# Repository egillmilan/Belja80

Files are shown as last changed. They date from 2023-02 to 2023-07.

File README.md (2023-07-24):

# Belja80
 
TKL keyboard based on the RP2040 microcontroller. Compatible with ANSI and ISO layout.
78338884-2CD3-49FE-B128-DA2AC7E8922D
CA066DF3-226C-4CC9-AC3D-376DD7F449F3
207D5793-591D-41C7-A5E0-8D16D3B497DB

# Flashing instructions
* Plug the keyboard into a computer and a drive named "RP2040" should appear. It might be necessary to hold down the boot button while plugging in the board for the drive to appear.
* Install [Adafruit circuitpython for the Raspberry Pi Pico](https://circuitpython.org/board/raspberry_pi_pico/), version 8 or newer. This is done by copying the .uf2 file to the RP2040 drive. The drive will dissapear briefly and a drive named "CIRCUITPY" will appear.
* Copy the folder named "kmk" from the [kmk_firmware-master repository](https://github.com/KMKfw/kmk_firmware) to the CIRCUIUTPY drive.
* Copy the supplied python files in the "Belja80_firmware" folder to the CIRCUITPY drive.

The keyboard should now work. When plugging in the keyboard next time, the board will not appear as a drive. To let the keyboard appear as a drive, hold in Esc while plugging the keyboard into your computer.

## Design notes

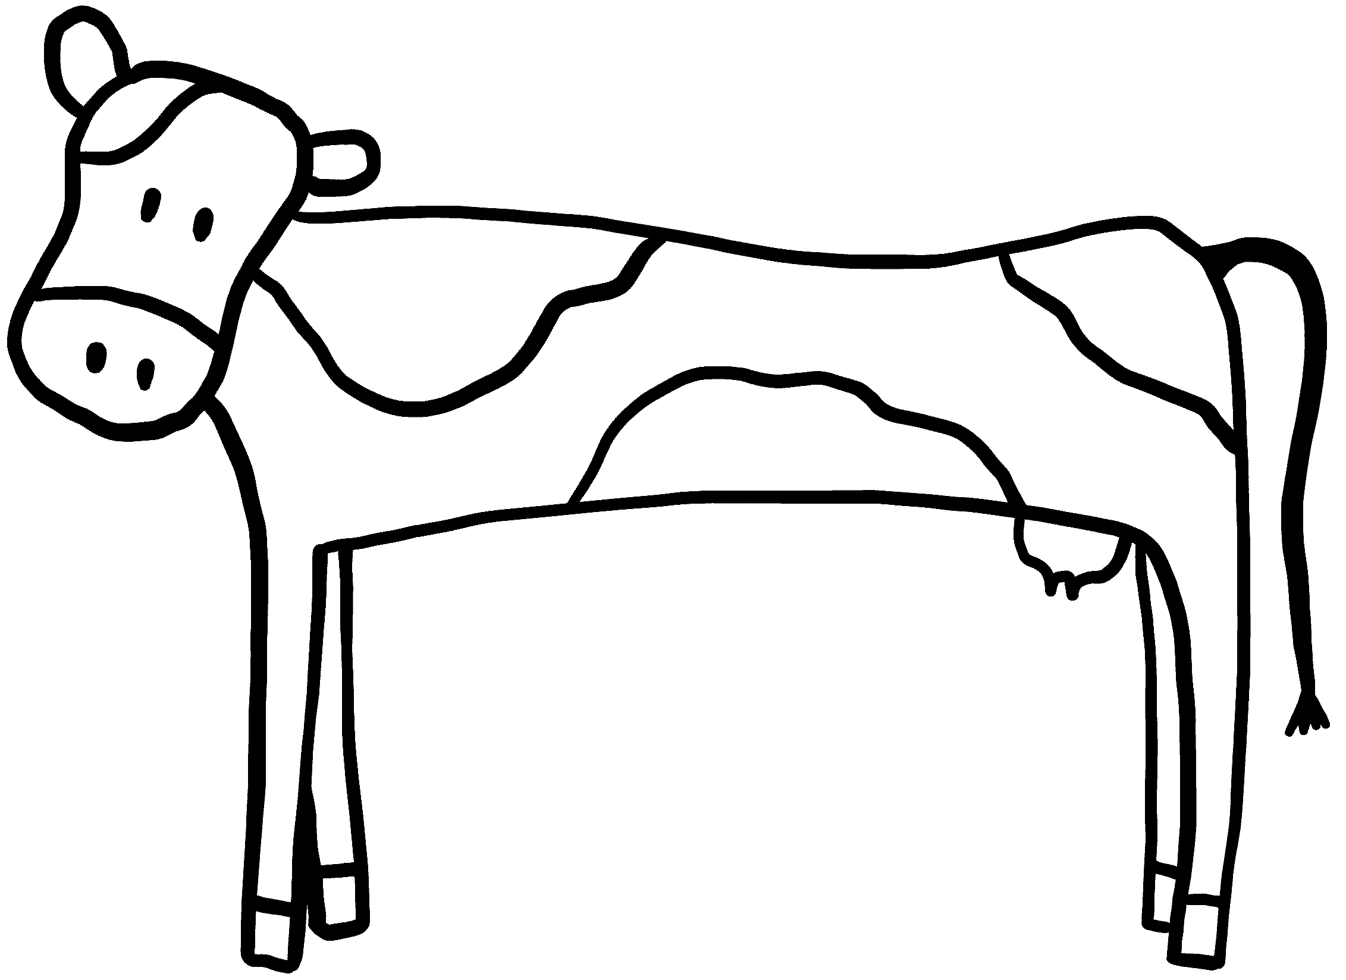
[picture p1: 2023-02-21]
belja80.jpg

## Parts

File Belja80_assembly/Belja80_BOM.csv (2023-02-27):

Comment | Designator | Footprint | LCSC Part Number
1uF | C1, C14 | 402 | C52923
30p | C2, C8 | 402 | C1570
100nF | C3, C4, C7, C9, C10, C11, C12, C13, C15, C16 | 402 | C1525
22uF | C5, C6 | CASE-A-3216 | C97062
SM4007PL | D1, D2, D3, D4, D5, D6, D7, D8, D9, D10, D11, D12, D13, D14, D15, D16, D17, D18, D19, D20, D21, D22, D23, D24, D25, D26, D27, D28, D29, D30, D31, D32, D33, D34, D35, D36, D37, D38, D39, D40, D41, D42, D43, D44, D45, D46, D47, D48, D49, D50, D51, D52, D53, D54, D55, D56, D57, D58, D59, D60, D61, D62, D63, D64, D65, D66, D67, D68, D69, D70, D71, D72, D73, D74, D75, D76, D77, D78, D79, D80, D81, D82, D83, D84, D85, D86, D87, D88, D89 | SOD-123FL | C64898
Green LED | D90 | 603 | C72043
500mA | F1 | 1206 | C206992
220R@100MHz | FB1 | 603 | C80165
USB_C_Receptacle | J1 | SMD | C2760486
1k | R1, R2, R8 | 402 | C11702
27R | R3, R6 | 402 | C226392
5k1 | R4, R5 | 603 | C23186
10k | R9 | 603 | C25804
TS-1187A-B-A-B | SW92,SW93 | SMD | C318884
RP2040 | U1 | LQFN-56(7x7) | C2040
AMS1117-3.3 | U2 | SOT-223-3 | C6186
W25Q16JVSSIQ | U3 | SOIC-8-208mil | C82317
12MHz | Y1 | SMD3225-4P | C9002

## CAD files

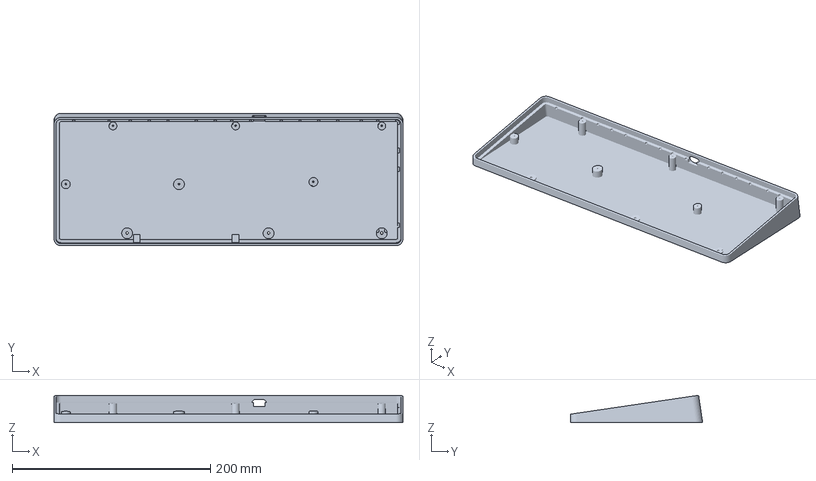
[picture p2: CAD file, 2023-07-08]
Belja80_case_3D_files/Belja80_Case_v2_2_whole.3mf
352.5 x 133.7 x 27.7 mm

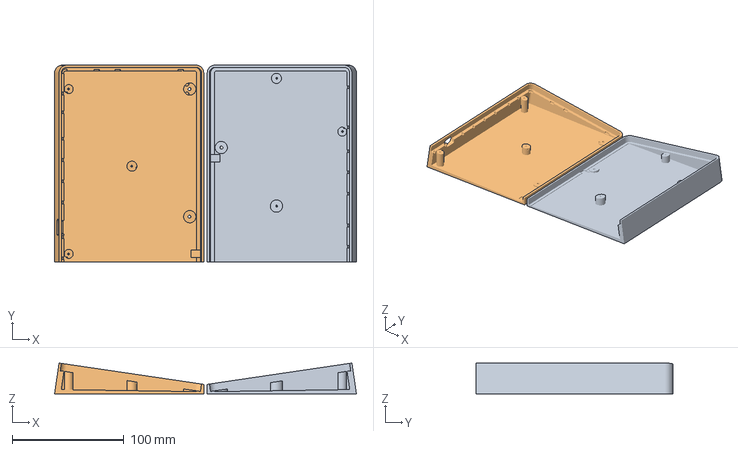
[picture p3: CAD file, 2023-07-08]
Belja80_case_3D_files/Belja80_Case_v2_2_split.3mf
270.5 x 176.2 x 27.7 mm
Case_L
Case_R

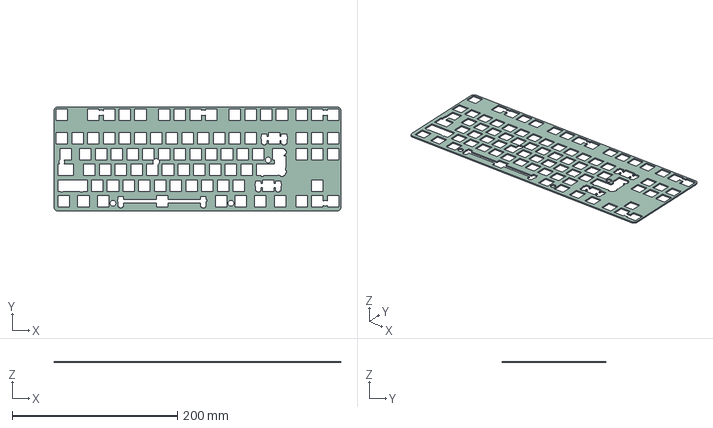
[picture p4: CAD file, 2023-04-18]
Belja80_plate/Belja80_plate.step
347.7 x 126.2 x 1.60 mm

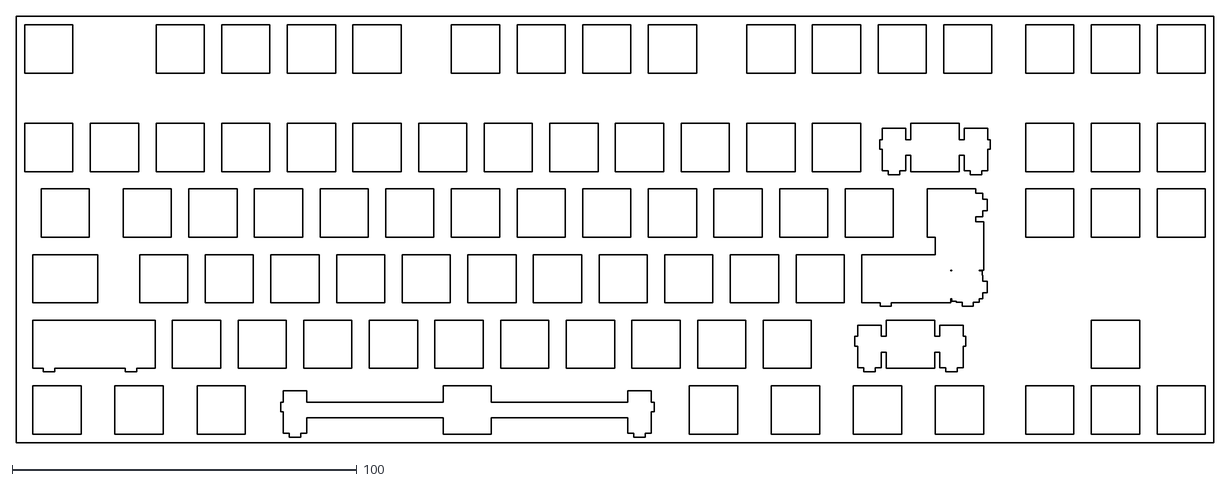
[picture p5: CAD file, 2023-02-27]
Belja80_plate/belja80_KLE.dxf
347.7 x 123.8

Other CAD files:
Belja80_case_3D_files/Belja80_Case_v2_2_split.stl
Belja80_case_3D_files/Belja80_Case_v2_2_whole.stl

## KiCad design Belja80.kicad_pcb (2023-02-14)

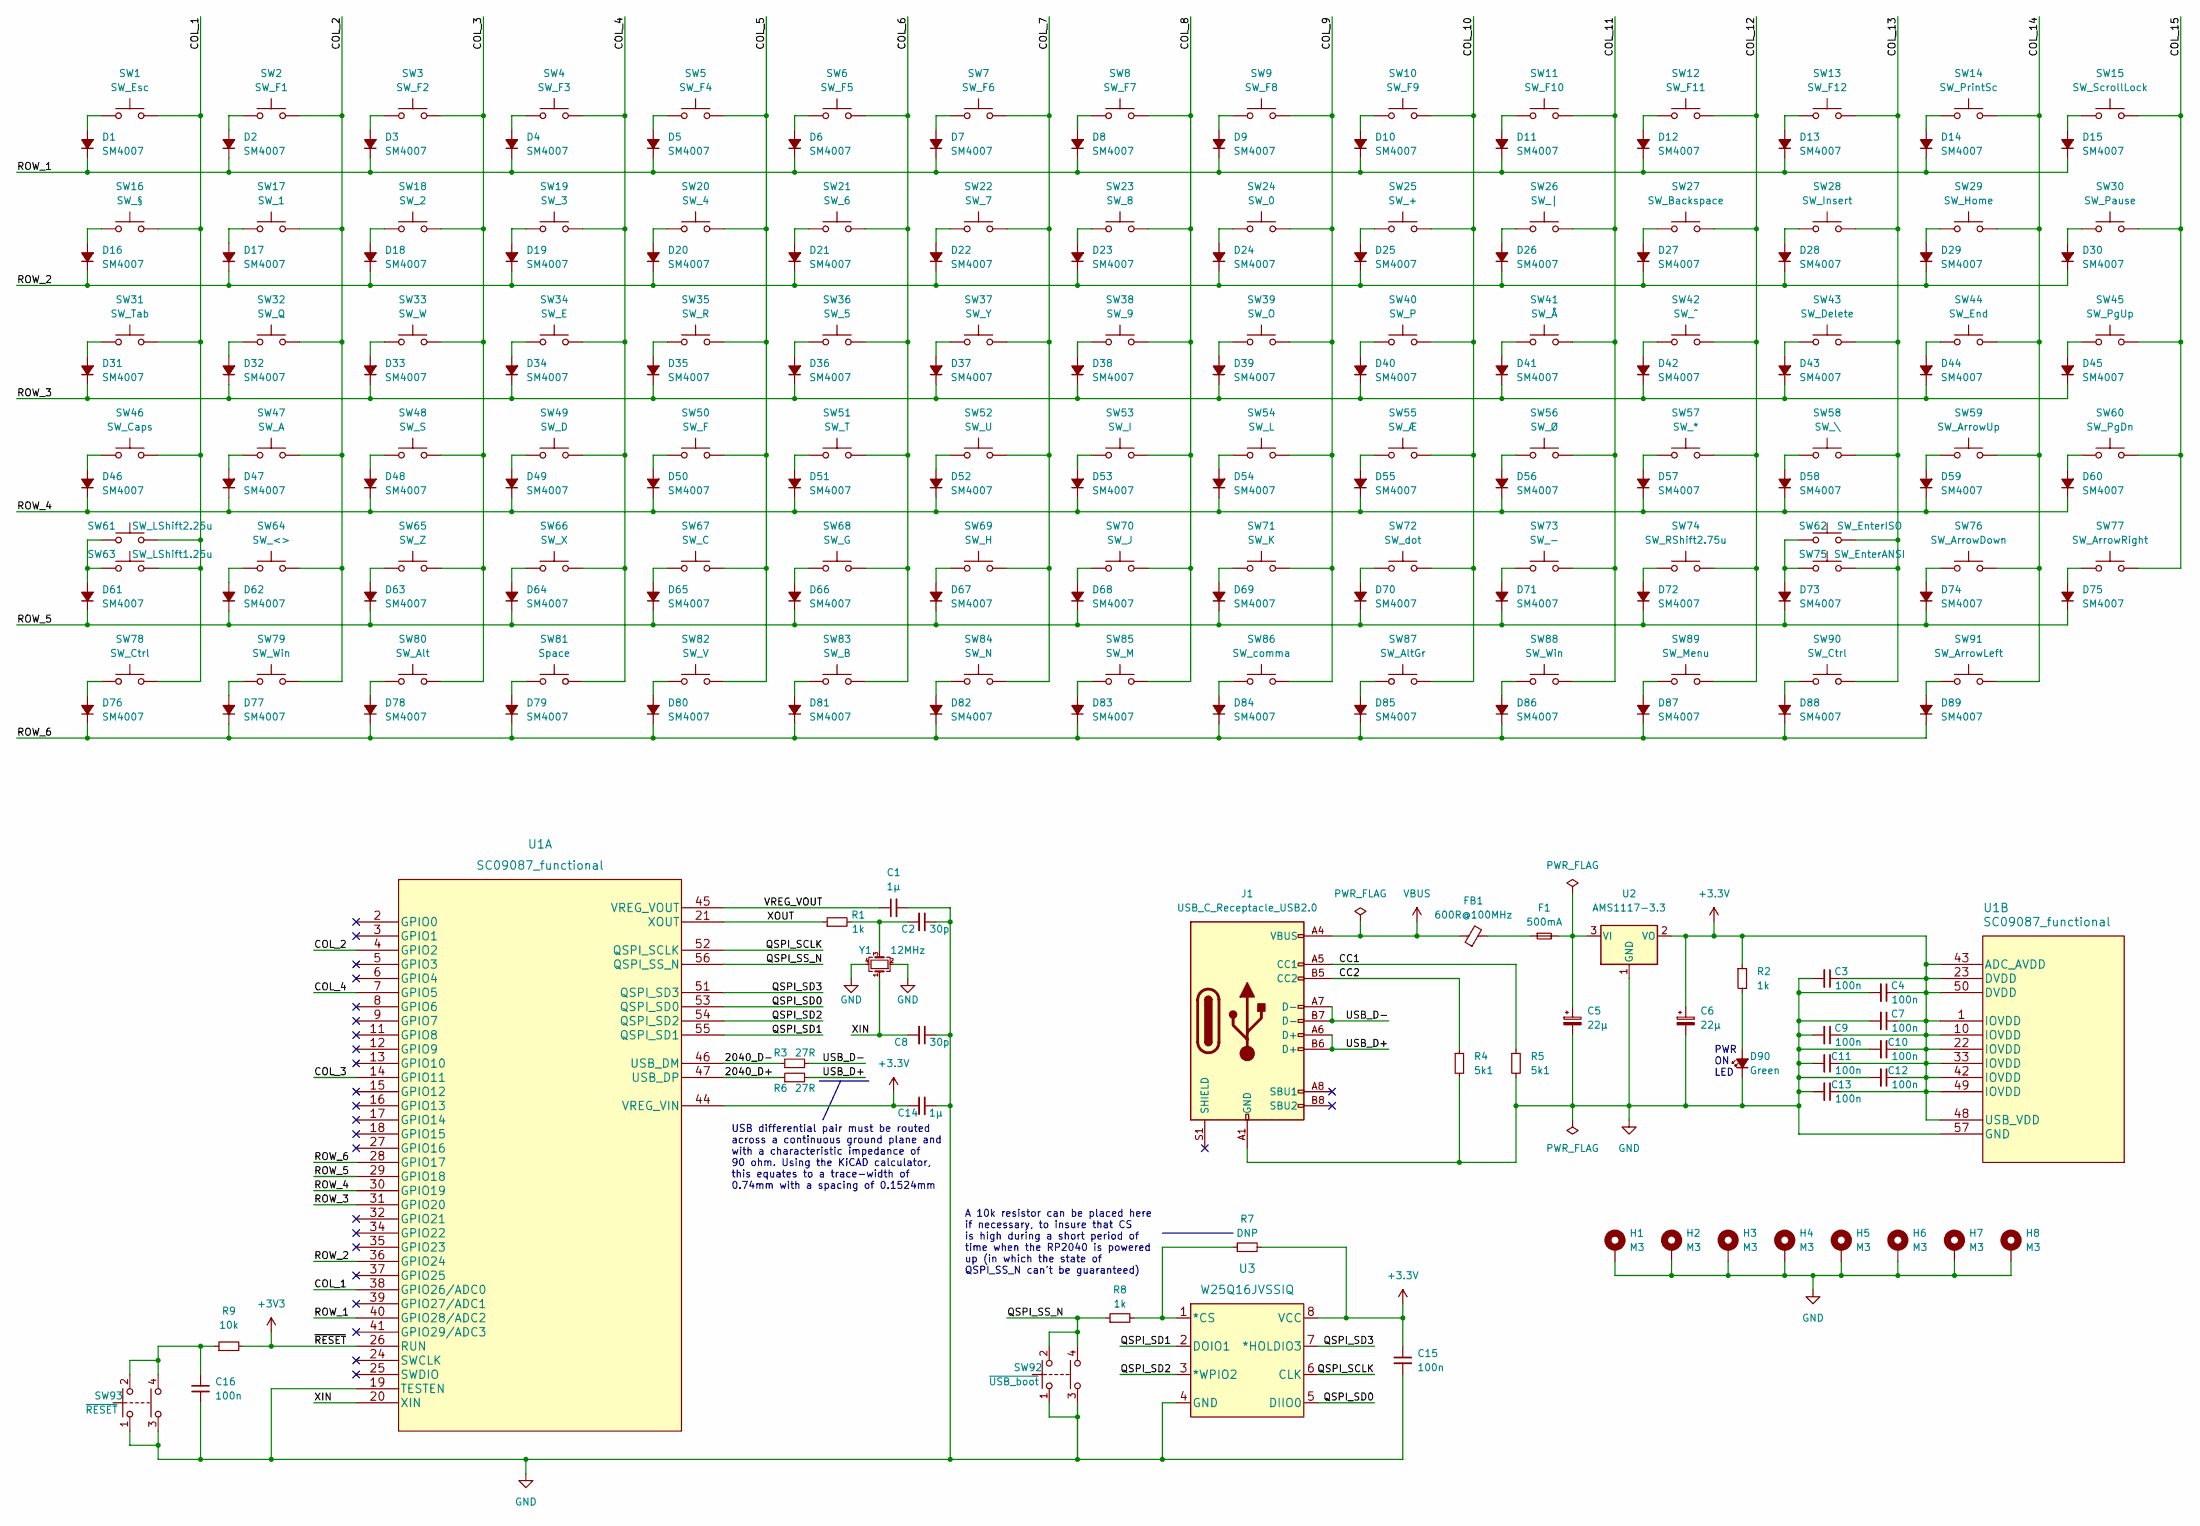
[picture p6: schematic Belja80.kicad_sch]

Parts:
C1, C14: 1µ; C_0402_1005Metric
C2, C8: 30p; C_0402_1005Metric
C3, C4, C7, C9, C10, C11, C12, C13, C15, C16: 100n; C_0402_1005Metric
C5, C6: 22µ; CP_EIA-3216-18_Kemet-A
D1, D2, D3, D4, D5, D6, D7, D8, D9, D10, D11, D12, D13, D14, D15, D16, D17, D18, D19, D20, D21, D22, D23, D24, D25, D26, D27, D28, D29, D30, D31, D32, D33, D34, D35, D36, D37, D38, D39, D40, D41, D42, D43, D44, D45, D46, D47, D48, D49, D50, D51, D52, D53, D54, D55, D56, D57, D58, D59, D60, D61, D62, D63, D64, D65, D66, D67, D68, D69, D70, D71, D72, D73, D74, D75, D76, D77, D78, D79, D80, D81, D82, D83, D84, D85, D86, D87, D88, D89: SM4007; D_SOD-123F
D90: Green; LED_0603_1608Metric
F1: 500mA; Fuse_1206_3216Metric
FB1: 600R@100MHz; L_0603_1608Metric
H1, H2, H3, H4, H5, H6, H7, H8: M3; MountingHole_3.2mm_M3_Pad_Via
J1: USB_C_Receptacle_USB2.0; USB_C_Receptacle_GCT_USB4085
R1, R2, R8: 1k; R_0603_1608Metric
R3, R6: 27R; R_0603_1608Metric
R4, R5: 5k1; R_0603_1608Metric
R7: DNP; R_0603_1608Metric
R9: 10k; R_0603_1608Metric
SW1: SW_Esc; SW_Cherry_MX_1.00u_PCB
SW2: SW_F1; SW_Cherry_MX_1.00u_PCB
SW3: SW_F2; SW_Cherry_MX_1.00u_PCB
SW4: SW_F3; SW_Cherry_MX_1.00u_PCB
SW5: SW_F4; SW_Cherry_MX_1.00u_PCB
SW6: SW_F5; SW_Cherry_MX_1.00u_PCB
SW7: SW_F6; SW_Cherry_MX_1.00u_PCB
SW8: SW_F7; SW_Cherry_MX_1.00u_PCB
SW9: SW_F8; SW_Cherry_MX_1.00u_PCB
SW10: SW_F9; SW_Cherry_MX_1.00u_PCB
SW11: SW_F10; SW_Cherry_MX_1.00u_PCB
SW12: SW_F11; SW_Cherry_MX_1.00u_PCB
SW13: SW_F12; SW_Cherry_MX_1.00u_PCB
SW14: SW_PrintSc; SW_Cherry_MX_1.00u_PCB
SW15: SW_ScrollLock; SW_Cherry_MX_1.00u_PCB
SW16: SW_§; SW_Cherry_MX_1.00u_PCB
SW17: SW_1; SW_Cherry_MX_1.00u_PCB
SW18: SW_2; SW_Cherry_MX_1.00u_PCB
SW19: SW_3; SW_Cherry_MX_1.00u_PCB
SW20: SW_4; SW_Cherry_MX_1.00u_PCB
SW21: SW_6; SW_Cherry_MX_1.00u_PCB
SW22: SW_7; SW_Cherry_MX_1.00u_PCB
SW23: SW_8; SW_Cherry_MX_1.00u_PCB
SW24: SW_0; SW_Cherry_MX_1.00u_PCB
SW25: SW_+; SW_Cherry_MX_1.00u_PCB
SW26: SW_|; SW_Cherry_MX_1.00u_PCB
SW27: SW_Backspace; SW_Cherry_MX_2.00u_PCB
SW28: SW_Insert; SW_Cherry_MX_1.00u_PCB
SW29: SW_Home; SW_Cherry_MX_1.00u_PCB
SW30: SW_Pause; SW_Cherry_MX_1.00u_PCB
SW31: SW_Tab; SW_Cherry_MX_1.50u_PCB
SW32: SW_Q; SW_Cherry_MX_1.00u_PCB
SW33: SW_W; SW_Cherry_MX_1.00u_PCB
SW34: SW_E; SW_Cherry_MX_1.00u_PCB
SW35: SW_R; SW_Cherry_MX_1.00u_PCB
SW36: SW_5; SW_Cherry_MX_1.00u_PCB
SW37: SW_Y; SW_Cherry_MX_1.00u_PCB
SW38: SW_9; SW_Cherry_MX_1.00u_PCB
SW39: SW_O; SW_Cherry_MX_1.00u_PCB
SW40: SW_P; SW_Cherry_MX_1.00u_PCB
SW41: SW_Å; SW_Cherry_MX_1.00u_PCB
SW42: SW_^; SW_Cherry_MX_1.00u_PCB
SW43: SW_Delete; SW_Cherry_MX_1.00u_PCB
SW44: SW_End; SW_Cherry_MX_1.00u_PCB
SW45: SW_PgUp; SW_Cherry_MX_1.00u_PCB
SW46: SW_Caps; SW_Cherry_MX_1.75u_PCB
SW47: SW_A; SW_Cherry_MX_1.00u_PCB
SW48: SW_S; SW_Cherry_MX_1.00u_PCB
SW49: SW_D; SW_Cherry_MX_1.00u_PCB
SW50: SW_F; SW_Cherry_MX_1.00u_PCB
SW51: SW_T; SW_Cherry_MX_1.00u_PCB
SW52: SW_U; SW_Cherry_MX_1.00u_PCB
SW53: SW_I; SW_Cherry_MX_1.00u_PCB
SW54: SW_L; SW_Cherry_MX_1.00u_PCB
SW55: SW_Æ; SW_Cherry_MX_1.00u_PCB
SW56: SW_Ø; SW_Cherry_MX_1.00u_PCB
SW57: SW_*; SW_Cherry_MX_1.00u_PCB
SW58: SW_\; SW_Cherry_MX_1.50u_PCB
SW59: SW_ArrowUp; SW_Cherry_MX_1.00u_PCB
SW60: SW_PgDn; SW_Cherry_MX_1.00u_PCB
SW61: SW_LShift2.25u; SW_Cherry_MX_2.25u_PCB
SW62: SW_EnterISO; SW_Cherry_MX_ISOEnter_PCB
SW63: SW_LShift1.25u; SW_Cherry_MX_1.25u_PCB
SW64: SW_<>; SW_Cherry_MX_1.00u_PCB
SW65: SW_Z; SW_Cherry_MX_1.00u_PCB
SW66: SW_X; SW_Cherry_MX_1.00u_PCB
SW67: SW_C; SW_Cherry_MX_1.00u_PCB
SW68: SW_G; SW_Cherry_MX_1.00u_PCB
SW69: SW_H; SW_Cherry_MX_1.00u_PCB
SW70: SW_J; SW_Cherry_MX_1.00u_PCB
SW71: SW_K; SW_Cherry_MX_1.00u_PCB
SW72: SW_dot; SW_Cherry_MX_1.00u_PCB
SW73: SW_-; SW_Cherry_MX_1.00u_PCB
SW74: SW_RShift2.75u; SW_Cherry_MX_2.75u_PCB
SW75: SW_EnterANSI; SW_Cherry_MX_2.25u_PCB
SW76: SW_ArrowDown; SW_Cherry_MX_1.00u_PCB
SW77: SW_ArrowRight; SW_Cherry_MX_1.00u_PCB
SW78, SW90: SW_Ctrl; SW_Cherry_MX_1.25u_PCB
SW79, SW88: SW_Win; SW_Cherry_MX_1.25u_PCB
SW80: SW_Alt; SW_Cherry_MX_1.25u_PCB
SW81: Space; SW_Cherry_MX_6.25u_PCB
SW82: SW_V; SW_Cherry_MX_1.00u_PCB
SW83: SW_B; SW_Cherry_MX_1.00u_PCB
SW84: SW_N; SW_Cherry_MX_1.00u_PCB
SW85: SW_M; SW_Cherry_MX_1.00u_PCB
SW86: SW_comma; SW_Cherry_MX_1.00u_PCB
SW87: SW_AltGr; SW_Cherry_MX_1.25u_PCB
SW89: SW_Menu; SW_Cherry_MX_1.25u_PCB
SW91: SW_ArrowLeft; SW_Cherry_MX_1.00u_PCB
SW92: ~{USB_boot}; SW_TS-1187A-B-A-B
SW93: ~{RESET}; SW_TS-1187A-B-A-B
U1: SC09087_functional; SC09087
U2: AMS1117-3.3; SOT-223-3_TabPin2
U3: W25Q16JVSSIQ
Y1: 12MHz; Crystal_SMD_3225-4Pin_3.2x2.5mm

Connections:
/2040_D+: R6.1, U1.47 (USB_DP)
/2040_D-: R3.1, U1.46 (USB_DM)
/CC1: J1.A5 (CC1), R5.1
/CC2: J1.B5 (CC2), R4.1
/COL_1: SW1.2, SW16.2, SW31.2, SW46.2, SW61.2, SW63.2, SW78.2, U1.38 (GPIO26/ADC0)
/COL_2: SW2.2, SW17.2, SW32.2, SW47.2, SW64.2, SW79.2, U1.4 (GPIO2)
/COL_3: SW3.2, SW18.2, SW33.2, SW48.2, SW65.2, SW80.2, U1.14 (GPIO11)
/COL_4: SW4.2, SW19.2, SW34.2, SW49.2, SW66.2, SW81.2, U1.7 (GPIO5)
/COL_5: SW5.2, SW20.2, SW35.2, SW50.2, SW67.2, SW82.2
/COL_6: SW6.2, SW21.2, SW36.2, SW51.2, SW68.2, SW83.2
/COL_7: SW7.2, SW22.2, SW37.2, SW52.2, SW69.2, SW84.2
/COL_8: SW8.2, SW23.2, SW38.2, SW53.2, SW70.2, SW85.2
/COL_9: SW9.2, SW24.2, SW39.2, SW54.2, SW71.2, SW86.2
/COL_10: SW10.2, SW25.2, SW40.2, SW55.2, SW72.2, SW87.2
/COL_11: SW11.2, SW26.2, SW41.2, SW56.2, SW73.2, SW88.2
/COL_12: SW12.2, SW27.2, SW42.2, SW57.2, SW74.2, SW89.2
/COL_13: SW13.2, SW28.2, SW43.2, SW58.2, SW62.2, SW75.2, SW90.2
/COL_14: SW14.2, SW29.2, SW44.2, SW59.2, SW76.2, SW91.2
/COL_15: SW15.2, SW30.2, SW45.2, SW60.2, SW77.2
/QSPI_SCLK: U1.52 (QSPI_SCLK), U3.6 (CLK)
/QSPI_SD0: U1.53 (QSPI_SD0), U3.5 (DIIO0)
/QSPI_SD1: U1.55 (QSPI_SD1), U3.2 (DOIO1)
/QSPI_SD2: U1.54 (QSPI_SD2), U3.3 (*WPIO2)
/QSPI_SD3: U1.51 (QSPI_SD3), U3.7 (*HOLDIO3)
/QSPI_SS_N: R8.1, SW92.2, SW92.4, U1.56 (QSPI_SS_N)
/ROW_1: D1.1 (K), D2.1 (K), D3.1 (K), D4.1 (K), D5.1 (K), D6.1 (K), D7.1 (K), D8.1 (K), D9.1 (K), D10.1 (K), D11.1 (K), D12.1 (K), D13.1 (K), D14.1 (K), D15.1 (K), U1.40 (GPIO28/ADC2)
/ROW_2: D16.1 (K), D17.1 (K), D18.1 (K), D19.1 (K), D20.1 (K), D21.1 (K), D22.1 (K), D23.1 (K), D24.1 (K), D25.1 (K), D26.1 (K), D27.1 (K), D28.1 (K), D29.1 (K), D30.1 (K), U1.36 (GPIO24)
/ROW_3: D31.1 (K), D32.1 (K), D33.1 (K), D34.1 (K), D35.1 (K), D36.1 (K), D37.1 (K), D38.1 (K), D39.1 (K), D40.1 (K), D41.1 (K), D42.1 (K), D43.1 (K), D44.1 (K), D45.1 (K), U1.31 (GPIO20)
/ROW_4: D46.1 (K), D47.1 (K), D48.1 (K), D49.1 (K), D50.1 (K), D51.1 (K), D52.1 (K), D53.1 (K), D54.1 (K), D55.1 (K), D56.1 (K), D57.1 (K), D58.1 (K), D59.1 (K), D60.1 (K), U1.30 (GPIO19)
/ROW_5: D61.1 (K), D62.1 (K), D63.1 (K), D64.1 (K), D65.1 (K), D66.1 (K), D67.1 (K), D68.1 (K), D69.1 (K), D70.1 (K), D71.1 (K), D72.1 (K), D73.1 (K), D74.1 (K), D75.1 (K), U1.29 (GPIO18)
/ROW_6: D76.1 (K), D77.1 (K), D78.1 (K), D79.1 (K), D80.1 (K), D81.1 (K), D82.1 (K), D83.1 (K), D84.1 (K), D85.1 (K), D86.1 (K), D87.1 (K), D88.1 (K), D89.1 (K), U1.28 (GPIO17)
/USB_D+: J1.A6 (D+), J1.B6 (D+), R6.2
/USB_D-: J1.A7 (D-), J1.B7 (D-), R3.2
/XIN: C8.2, U1.20 (XIN), Y1.1
/XOUT: R1.1, U1.21 (XOUT)
GND: C1.2, C2.1, C3.2, C4.2, C5.2, C6.2, C7.2, C8.1, C9.2, C10.2, C11.2, C12.2, C13.2, C14.2, C15.2, C16.2, D90.1 (K), H1.1, H2.1, H3.1, H4.1, H5.1, H6.1, H7.1, H8.1, J1.A1 (GND), J1.A12 (GND), J1.B1 (GND), J1.B12 (GND), R4.2, R5.2, SW92.1, SW92.3, SW93.1, SW93.3, U1.19 (TESTEN), U1.57 (GND), U2.1 (GND), U3.4 (GND), Y1.2, Y1.4
unnamed: C2.2, R1.2, Y1.3
unnamed: C16.1, R9.1, SW93.2, SW93.4
unnamed: D1.2 (A), SW1.1
unnamed: D2.2 (A), SW2.1
unnamed: D3.2 (A), SW3.1
unnamed: D4.2 (A), SW4.1
unnamed: D5.2 (A), SW5.1
unnamed: D6.2 (A), SW6.1
unnamed: D7.2 (A), SW7.1
unnamed: D8.2 (A), SW8.1
unnamed: D9.2 (A), SW9.1
unnamed: D10.2 (A), SW10.1
unnamed: D11.2 (A), SW11.1
unnamed: D12.2 (A), SW12.1
unnamed: D13.2 (A), SW13.1
unnamed: D14.2 (A), SW14.1
unnamed: D15.2 (A), SW15.1
unnamed: D16.2 (A), SW16.1
unnamed: D17.2 (A), SW17.1
unnamed: D18.2 (A), SW18.1
unnamed: D19.2 (A), SW19.1
unnamed: D20.2 (A), SW20.1
unnamed: D21.2 (A), SW21.1
unnamed: D22.2 (A), SW22.1
unnamed: D23.2 (A), SW23.1
unnamed: D24.2 (A), SW24.1
unnamed: D25.2 (A), SW25.1
unnamed: D26.2 (A), SW26.1
unnamed: D27.2 (A), SW27.1
unnamed: D28.2 (A), SW28.1
unnamed: D29.2 (A), SW29.1
unnamed: D30.2 (A), SW30.1
unnamed: D31.2 (A), SW31.1
unnamed: D32.2 (A), SW32.1
unnamed: D33.2 (A), SW33.1
unnamed: D34.2 (A), SW34.1
unnamed: D35.2 (A), SW35.1
unnamed: D36.2 (A), SW36.1
unnamed: D37.2 (A), SW37.1
unnamed: D38.2 (A), SW38.1
unnamed: D39.2 (A), SW39.1
unnamed: D40.2 (A), SW40.1
unnamed: D41.2 (A), SW41.1
unnamed: D42.2 (A), SW42.1
unnamed: D43.2 (A), SW43.1
unnamed: D44.2 (A), SW44.1
unnamed: D45.2 (A), SW45.1
unnamed: D46.2 (A), SW46.1
unnamed: D47.2 (A), SW47.1
unnamed: D48.2 (A), SW48.1
unnamed: D49.2 (A), SW49.1
unnamed: D50.2 (A), SW50.1
unnamed: D51.2 (A), SW51.1
unnamed: D52.2 (A), SW52.1
unnamed: D53.2 (A), SW53.1
unnamed: D54.2 (A), SW54.1
unnamed: D55.2 (A), SW55.1
unnamed: D56.2 (A), SW56.1
unnamed: D57.2 (A), SW57.1
unnamed: D58.2 (A), SW58.1
unnamed: D59.2 (A), SW59.1
unnamed: D60.2 (A), SW60.1
unnamed: D61.2 (A), SW61.1, SW63.1
unnamed: D62.2 (A), SW64.1
unnamed: D63.2 (A), SW65.1
unnamed: D64.2 (A), SW66.1
unnamed: D65.2 (A), SW67.1
unnamed: D66.2 (A), SW68.1
unnamed: D67.2 (A), SW69.1
unnamed: D68.2 (A), SW70.1
unnamed: D69.2 (A), SW71.1
unnamed: D70.2 (A), SW72.1
unnamed: D71.2 (A), SW73.1
unnamed: D72.2 (A), SW74.1
unnamed: D73.2 (A), SW62.1, SW75.1
unnamed: D74.2 (A), SW76.1
unnamed: D75.2 (A), SW77.1
unnamed: D76.2 (A), SW78.1
unnamed: D77.2 (A), SW79.1
unnamed: D78.2 (A), SW80.1
unnamed: D79.2 (A), SW81.1
unnamed: D80.2 (A), SW82.1
unnamed: D81.2 (A), SW83.1
unnamed: D82.2 (A), SW84.1
unnamed: D83.2 (A), SW85.1
unnamed: D84.2 (A), SW86.1
unnamed: D85.2 (A), SW87.1
unnamed: D86.2 (A), SW88.1
unnamed: D87.2 (A), SW89.1
unnamed: D88.2 (A), SW90.1
unnamed: D89.2 (A), SW91.1
unnamed: D90.2 (A), R2.2
unnamed: F1.1, FB1.2
unnamed: C5.1, F1.2, U2.3 (VI)
unnamed: R7.1, R8.2, U3.1 (*CS)
VBUS: FB1.1, J1.A4 (VBUS), J1.A9 (VBUS), J1.B4 (VBUS), J1.B9 (VBUS)

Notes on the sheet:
PWR ON LED
A 10k resistor can be placed here if necessary, to insure that CS is high during a short period of time when the RP2040 is powered up (in which the state of QSPI_SS_N can't be guaranteed)
USB differential pair must be routed across a continuous ground plane and with a characteristic impedance of 90 ohm. Using the KiCAD calculator, this equates to a trace-width of 0.74mm with a spacing of 0.1524mm

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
Board: 2 copper layers, 223 parts (124 on the bottom side), 134 nets, no tracks yet.

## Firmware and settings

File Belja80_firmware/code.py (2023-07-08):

#ISO LAYOUT

import microcontroller as uC

from kb import KMKKeyboard
from kmk.keys import KC

keyboard = KMKKeyboard()

keyboard.keymap = [
    [KC.ESC,    KC.F1,      KC.F2,      KC.F3,  KC.F4,  KC.F5,  KC.F6,  KC.F7,  KC.F8,      KC.F9,      KC.F10,     KC.F11,     KC.F12,     KC.PSCR,    KC.SLCK,
     KC.GRV,    KC.N1,      KC.N2,      KC.N3,  KC.N4,  KC.N6,  KC.N7,  KC.N8,  KC.N0,      KC.MINS,    KC.EQL,     KC.BSPC,    KC.INS,     KC.HOME,    KC.PAUS,
     KC.TAB,    KC.Q,       KC.W,       KC.E,   KC.R,   KC.N5,  KC.Y,   KC.N9,  KC.O,       KC.P,       KC.LBRC,    KC.RBRC,    KC.DEL,     KC.END,     KC.PGUP,
     KC.CAPS,   KC.A,       KC.S,       KC.D,   KC.F,   KC.T,   KC.U,   KC.I,   KC.L,       KC.SCLN,    KC.QUOT,    KC.NUHS,    KC.NO,      KC.UP,      KC.PGDN,
     KC.LSFT,   KC.NUBS,    KC.Z,       KC.X,   KC.C,   KC.G,   KC.H,   KC.J,   KC.K,       KC.DOT,     KC.SLSH,    KC.RSFT,    KC.ENT,     KC.DOWN,    KC.RGHT,
     KC.LCTL,   KC.LGUI,    KC.LALT,    KC.SPC, KC.V,   KC.B,   KC.N,   KC.M,   KC.COMM,    KC.RALT,    KC.RGUI,    KC.APP,     KC.RCTL,    KC.LEFT,    KC.NO,
    ]
]

if __name__ == '__main__':
    keyboard.go()

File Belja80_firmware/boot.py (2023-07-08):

import supervisor
import board
import digitalio
import storage
import usb_cdc
import usb_hid

from kb import KMKKeyboard
from kmk.scanners import DiodeOrientation


# If this key is held during boot, don't run the code which hides the storage and disables serial
# This will use the first row/col pin. Feel free to change it if you want it to be another pin
col = digitalio.DigitalInOut(KMKKeyboard.col_pins[0])
row = digitalio.DigitalInOut(KMKKeyboard.row_pins[0])

if KMKKeyboard.diode_orientation == DiodeOrientation.COLUMNS:
    col.switch_to_output(value=True)
    row.switch_to_input(pull=digitalio.Pull.DOWN)
else:
    col.switch_to_input(pull=digitalio.Pull.DOWN)
    row.switch_to_output(value=True)

if not row.value:
    storage.disable_usb_drive()
    # Equivalent to usb_cdc.enable(console=False, data=False)
    usb_cdc.disable()
    usb_hid.enable((usb_hid.Device.KEYBOARD),boot_device=1)
    # usb_hid.enable((usb_hid.Device.KEYBOARD,))

row.deinit()
col.deinit()

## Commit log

2023-02-14 Rough layout
    [Belja80.kicad_pcb]
2023-02-18 Component layout
    [Belja80.kicad_sch]
2023-02-20 routing µC section and silkscreen
    [Belja80.kicad_sch]
2023-02-24 Stepped Caps Lock support
    [Belja80.kicad_sch]
2023-02-27 Added plate
    [Belja80_plate.kicad_pcb, Belja80_plate.kicad_sch, belja80_KLE.dxf]
2023-02-27 Ready for production
    [Belja80-B_Cu.gbl, Belja80-B_Mask.gbs, Belja80-B_Paste.gbp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]
2023-04-18 3D model
    [Belja80_plate.step]
2023-07-08 Added case 3D files
    [Belja80_Case_v2_2_split.3mf, Belja80_Case_v2_2_split.stl, Belja80_Case_v2_2_whole.3mf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]
